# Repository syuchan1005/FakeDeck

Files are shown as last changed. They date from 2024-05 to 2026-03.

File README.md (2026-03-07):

# Fakedeck
Using raspberry pi pico as a stream deck

## Avaiable devices

|Mk2|Plus|
|:--:|:--:|
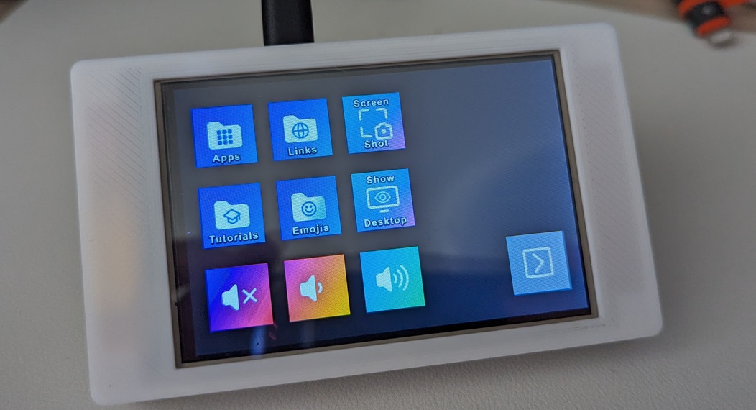
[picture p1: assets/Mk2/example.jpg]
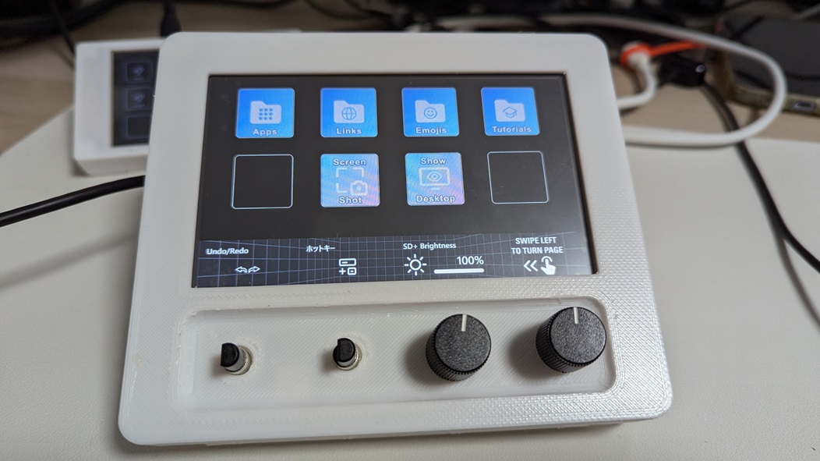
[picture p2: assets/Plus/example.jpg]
|||

## How to create : StreamDeck Mk.2
### Parts
- Raspberry Pi Pico
- ILI9488 TFT with Touch: [AliExpress](https://www.aliexpress.com/item/32985467436.html)
> [!IMPORTANT]
> Make sure to select "touch screen"
- Solder, wire, etc.
- 3D printers for creating a case - [Top](./assets/Mk2/Case%20-%20Top.stl), [Bottom](./assets/Mk2/Case%20-%20Bottom.stl)
- M3 x 6mm screw *4

### Wire
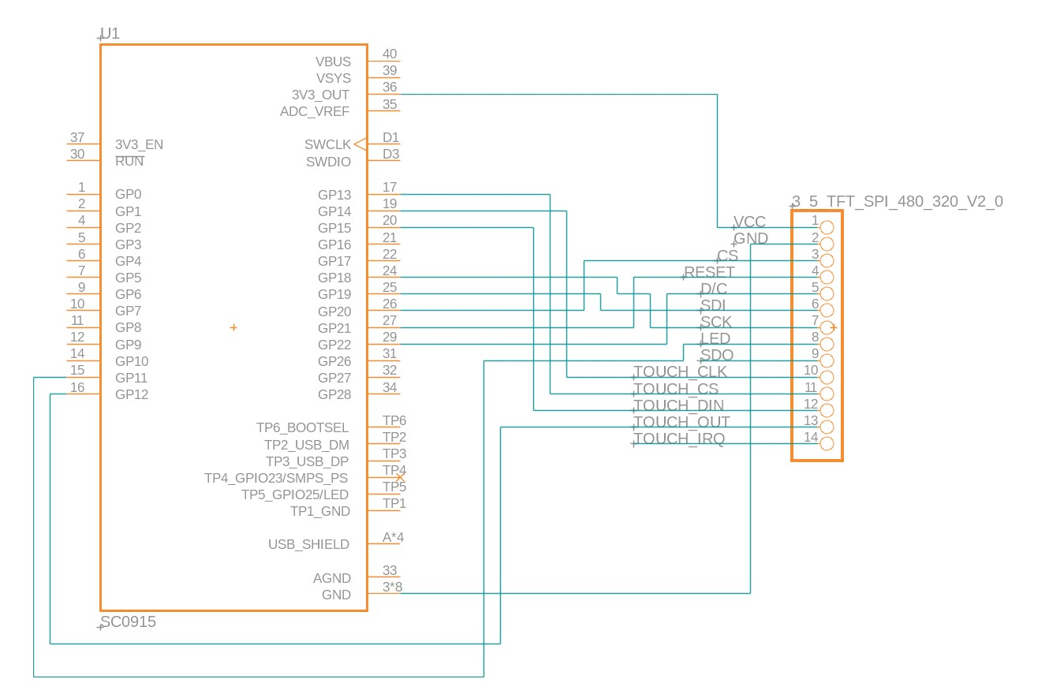
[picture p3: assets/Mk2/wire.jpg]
wire

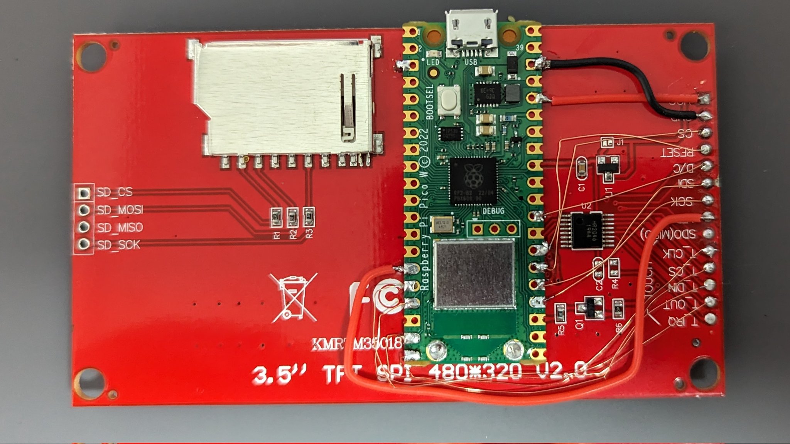
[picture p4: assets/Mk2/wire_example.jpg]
wire example


> [!NOTE]
> LCD uses 90 mA. 
> In the example, the back of the LCD is shaved and soldered to hold the pico in place.

### Build
1. Setup [PlatformIO IDE](https://platformio.org/platformio-ide)
2. Clone and open this project
3. Change environment to `pico_deckMk2`
4. Build .uf2 file!

## How to create : StreamDeck+
### Parts
- Raspberry Pi Pico W
- SSD1963 TFT with Touch: [AliExpress](https://www.aliexpress.com/item/1005006305412643.html)
> [!IMPORTANT]
> Make sure to select "resistive touch"
- Rotary encoder with switch (PEC12R-4220F-S0024) * 4: [Digikey](https://www.digikey.jp/short/jrrh2j7r), [Monotaro](https://www.monotaro.com/p/3483/7593/)
- Stripboard(approx. 120 x 90 (mm)) or Order PCB
- 3D printers for creating a case - [Top](./assets/Plus/Case%20-%20Top.stl), [Bottom body](./assets/Plus/Case%20-%20Bottom%20body.stl), [Bottom base](./assets/Plus/Case%20-%20Bottom%20base.stl), [Bottom bridge](./assets/Plus/Case%20-%20Bottom%20bridge.stl)
- M3 x 6mm screw *4
- Resistors: 47Ω, 120Ω, 220Ω, 470Ω, 1kΩ

> These resistors are used in the switch's ladder circuit. Any other value is acceptable as long as it is a constant multiple of the specified resistance. If using resistors other than these, modify `SW_PATTERNS` in [Encoder.hpp](./src/input/Encoder.hpp).

### Wire
wire_plus
|Front|Back|
|:--:|:--:|
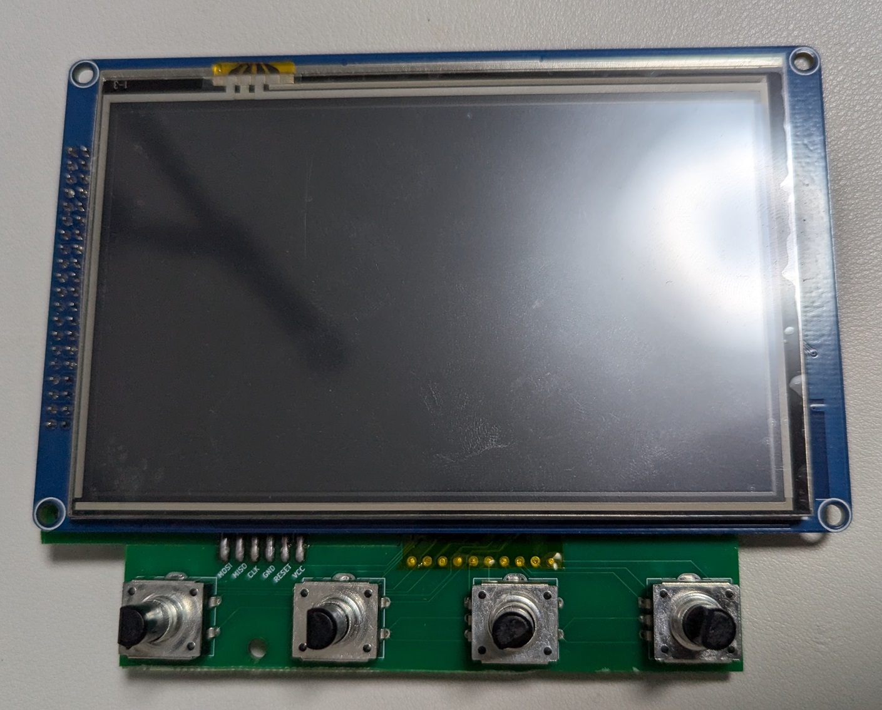
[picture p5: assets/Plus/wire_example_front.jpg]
wire_plus example_front
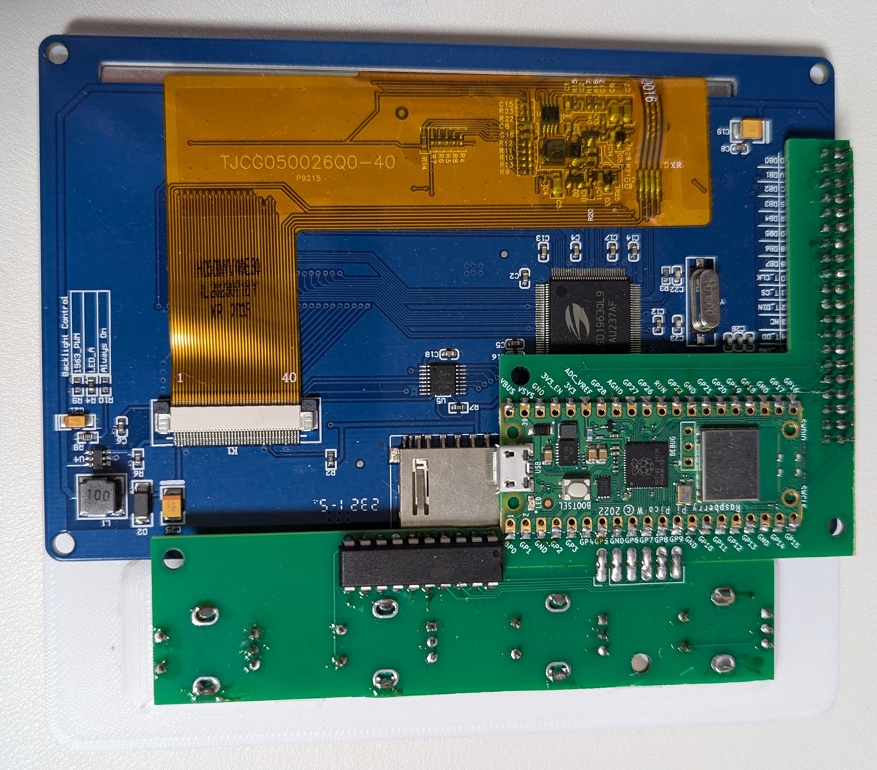
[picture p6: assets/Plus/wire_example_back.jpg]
wire_plus example_back
|||

> These are for the old PCB.

### projects

#### pico_avrisp_wifi
> not used
Write to avr microcontroller (attiny2313) using Raspberry Pi Pico W via WiFi

This project access WiFi AP. You should copy `config.sample.ini` to `config.ini`, and change values to your Wifi settings.

> [!NOTE]
> In my enviroment, [avrdude](https://github.com/avrdudes/avrdude) can not communicate with Raspberry Pi Pico via usb serial. So, It write to avr microcontroller via WiFi.

> [!IMPORTANT]
> In my environment, avrdude 6.3(PlatformIO embedded version) can not write via WiFi. Please update to **^7.3**. (You can replace files in `tool-avrdude` package)

#### avr
> not used
Get the four rotary encoder with push switch values via SPI.

### Build
#### Custom PCB
This project includes the [kicad project](./assets/Plus/kicad).

> [!WARNING]
> It includes gerber files, but they are for the old PCB.

#### Hardware
Solder the rotary encoders with reference to the [kicad project](./assets/Plus/kicad), making sure that the Screen display area is correct before soldering the rotary encoders.

#### Software
1. Setup [PlatformIO IDE](https://platformio.org/platformio-ide)
2. Clone and open this project
3. Change environment to `pico_deckPlus`, build and upload.

## Tips
- [HID Explorer](https://nondebug.github.io/webhid-explorer/) is an easy HID testing tool using WebHID
- Reboot device and enter bootsel mode: Send `[02, FF]` to the output report
- Reboot device: Send `[02, FE]` to the output report

## Reference
- [ESP8266AVRISP](https://github.com/esp8266/Arduino/tree/19b7a29720a6f2c95d06e2ea4baa335dcf32e68f/libraries/ESP8266AVRISP)
- [avr-usi-spi](https://github.com/tessel/avr-usi-spi/blob/77ce496d6bc404684158e619695c2fb7bc76815a/spi_via_usi_driver.c)

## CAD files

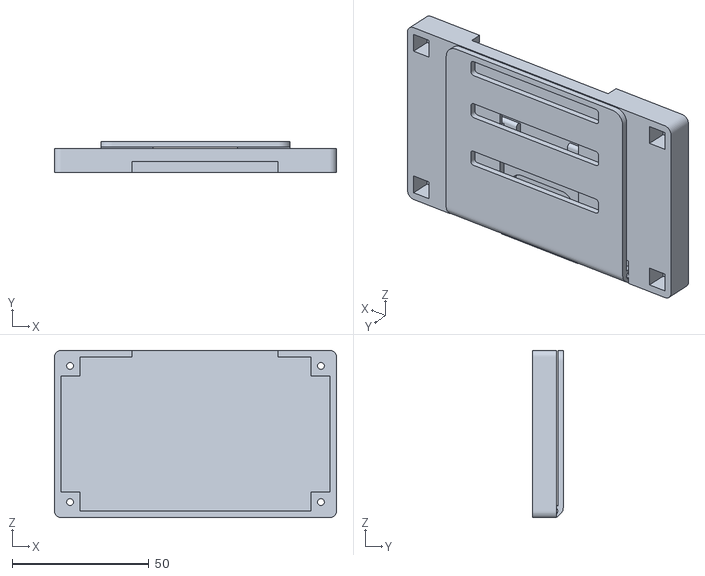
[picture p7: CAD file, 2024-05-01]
assets/Mk2/Case - Bottom.stl
103.3 x 11.2 x 61.3

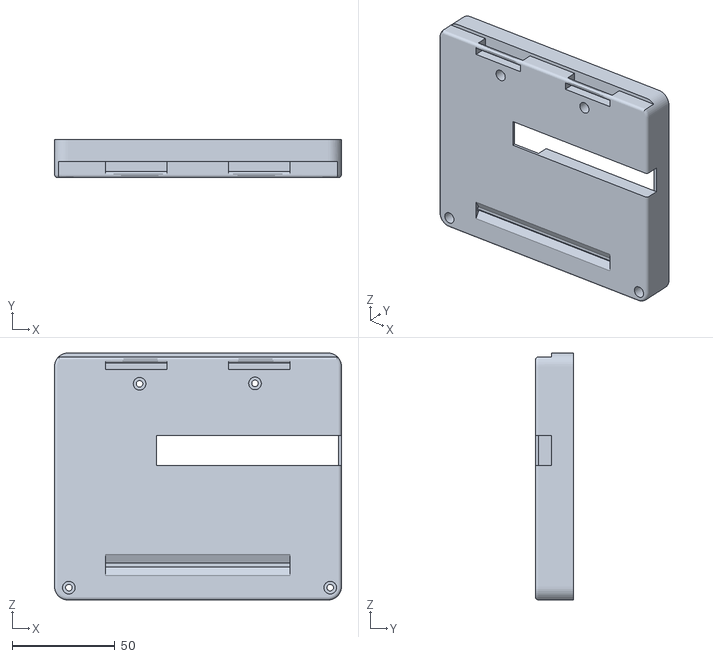
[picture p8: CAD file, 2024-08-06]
assets/Plus/Bottom body.stl
140.0 x 18.7 x 120.4

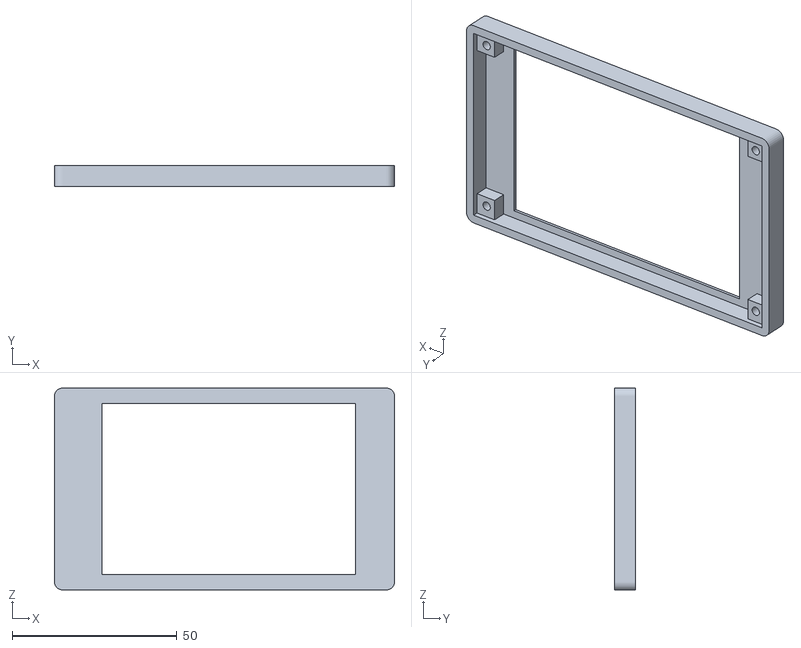
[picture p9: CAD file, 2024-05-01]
assets/Mk2/Case - Top.stl
103.3 x 6.30 x 61.3

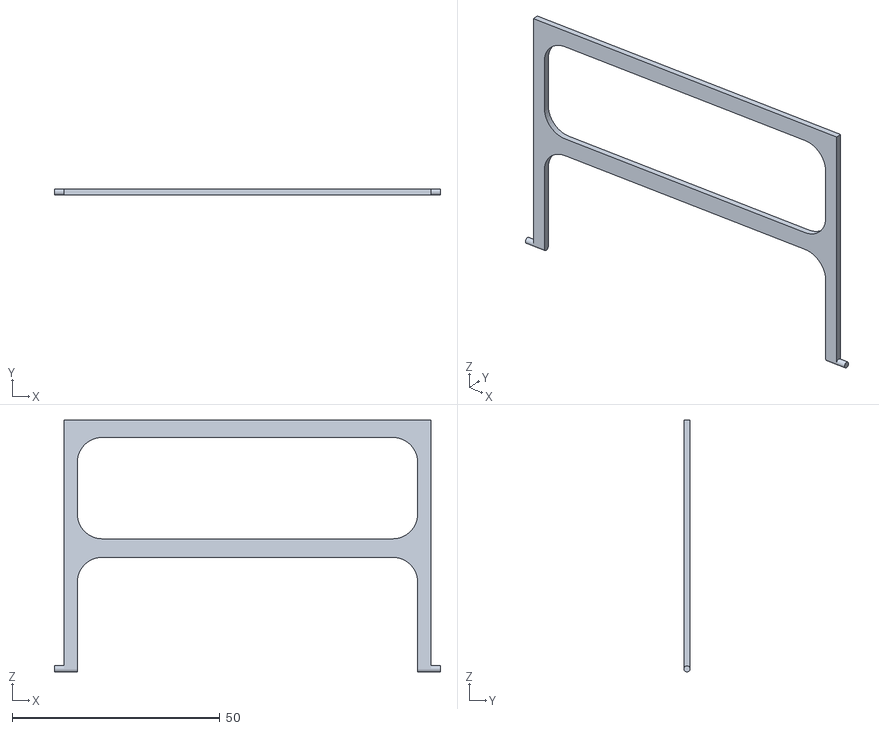
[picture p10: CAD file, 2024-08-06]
assets/Plus/Case - Bottom bridge.stl
93.0 x 1.50 x 60.7

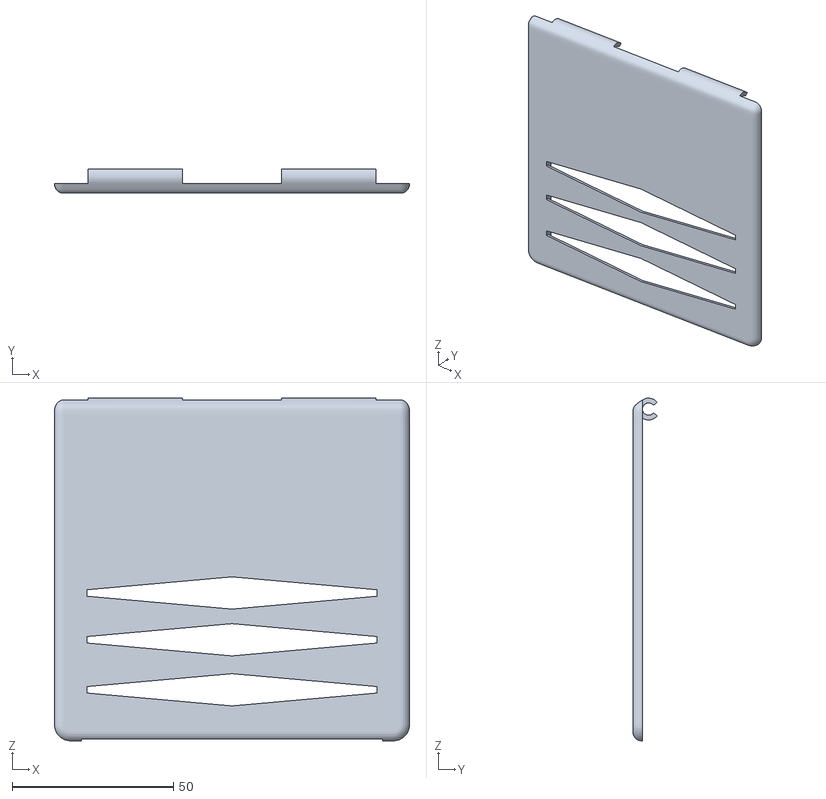
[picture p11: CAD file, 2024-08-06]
assets/Plus/Case - bottom base.stl
110.0 x 7.59 x 106.2

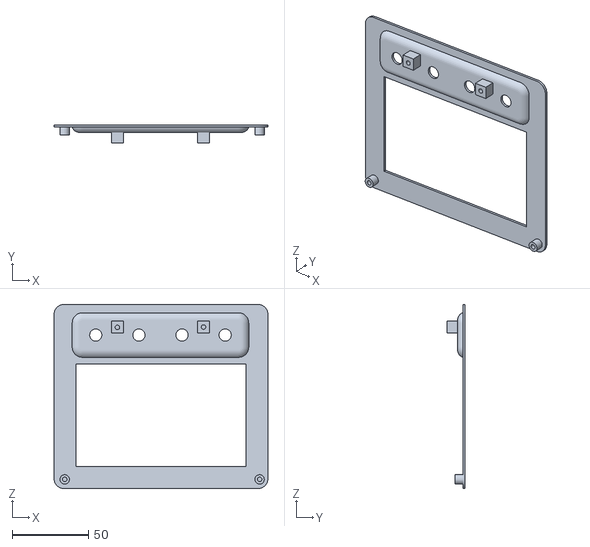
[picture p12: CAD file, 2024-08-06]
assets/Plus/Case - Top.stl
140.0 x 11.9 x 120.4

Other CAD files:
assets/Plus/Case - bottom body.stl
assets/Plus/Case.f3d

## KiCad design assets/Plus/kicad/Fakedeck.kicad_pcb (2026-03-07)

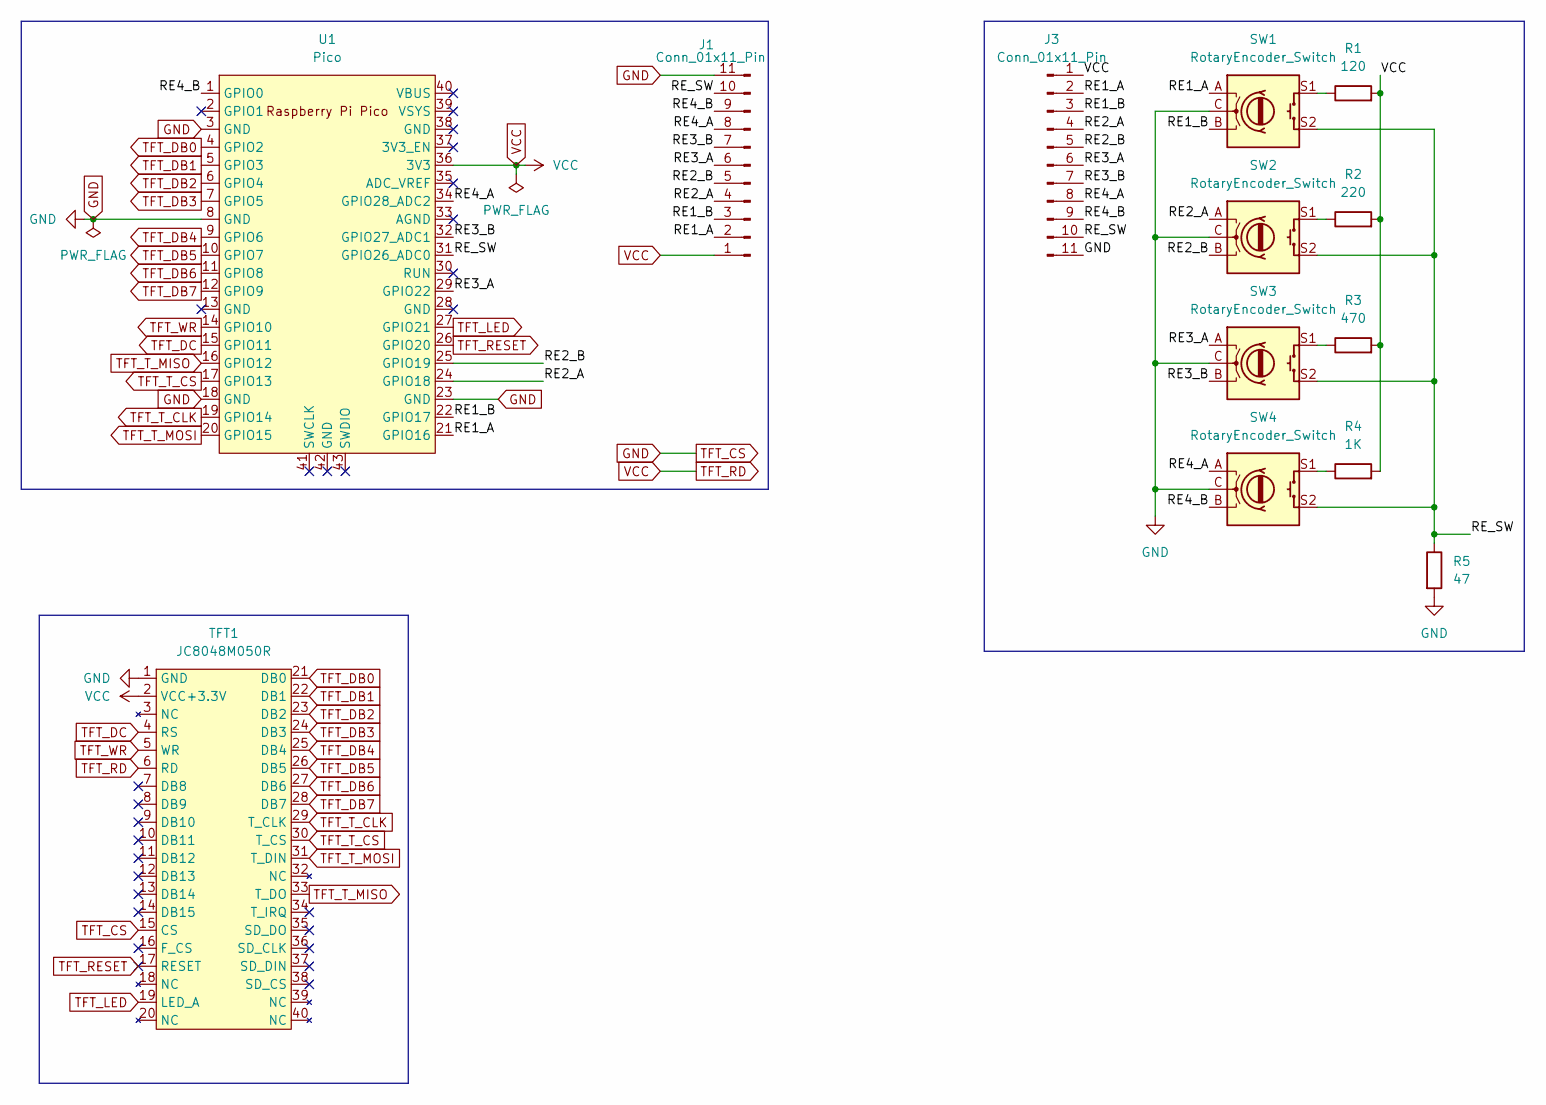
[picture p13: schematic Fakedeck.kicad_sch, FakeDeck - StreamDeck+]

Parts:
J1, J3: Conn_01x11_Pin; PinHeader_Castellated_1x11_P2.54mm_Vertical
R1: 120; R_Axial_DIN0207_L6.3mm_D2.5mm_P7.62mm_Horizontal
R2: 220; R_Axial_DIN0207_L6.3mm_D2.5mm_P7.62mm_Horizontal
R3: 470; R_Axial_DIN0207_L6.3mm_D2.5mm_P7.62mm_Horizontal
R4: 1K; R_Axial_DIN0207_L6.3mm_D2.5mm_P7.62mm_Horizontal
R5: 47; R_Axial_DIN0207_L6.3mm_D2.5mm_P7.62mm_Horizontal
SW1, SW2, SW3, SW4: RotaryEncoder_Switch; 3D_RotaryEncoder_Bourns_Vertical_PEC12R-3x17F-Sxxxx
TFT1: JC8048M050R; JC8048M050R_PinHeader
U1: Pico; RPi_Pico_SMD_TH

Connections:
/RE1_A: J1.2, J3.2, SW1.A, U1.21 (GPIO16)
/RE1_B: J1.3, J3.3, SW1.B, U1.22 (GPIO17)
/RE2_A: J1.4, J3.4, SW2.A, U1.24 (GPIO18)
/RE2_B: J1.5, J3.5, SW2.B, U1.25 (GPIO19)
/RE3_A: J1.6, J3.6, SW3.A, U1.29 (GPIO22)
/RE3_B: J1.7, J3.7, SW3.B, U1.32 (GPIO27_ADC1)
/RE4_A: J1.8, J3.8, SW4.A, U1.34 (GPIO28_ADC2)
/RE4_B: J1.9, J3.9, SW4.B, U1.1 (GPIO0)
/RE_SW: J1.10, J3.10, R5.1, SW1.S2, SW2.S2, SW3.S2, SW4.S2, U1.31 (GPIO26_ADC0)
GND: J1.11, J3.11, R5.2, SW1.C, SW2.C, SW3.C, SW4.C, TFT1.1 (GND), TFT1.15 (CS), U1.3 (GND), U1.8 (GND), U1.18 (GND), U1.23 (GND)
unnamed: R1.1, SW1.S1
unnamed: R2.1, SW2.S1
unnamed: R3.1, SW3.S1
unnamed: R4.1, SW4.S1
TFT_DB0: TFT1.21 (DB0), U1.4 (GPIO2)
TFT_DB1: TFT1.22 (DB1), U1.5 (GPIO3)
TFT_DB2: TFT1.23 (DB2), U1.6 (GPIO4)
TFT_DB3: TFT1.24 (DB3), U1.7 (GPIO5)
TFT_DB4: TFT1.25 (DB4), U1.9 (GPIO6)
TFT_DB5: TFT1.26 (DB5), U1.10 (GPIO7)
TFT_DB6: TFT1.27 (DB6), U1.11 (GPIO8)
TFT_DB7: TFT1.28 (DB7), U1.12 (GPIO9)
TFT_DC: TFT1.4 (RS), U1.15 (GPIO11)
TFT_LED: TFT1.19 (LED_A), U1.27 (GPIO21)
TFT_RD: J1.1, J3.1, R1.2, R2.2, R3.2, R4.2, TFT1.2 (VCC+3.3V), TFT1.6 (RD), U1.36 (3V3)
TFT_RESET: TFT1.17 (RESET), U1.26 (GPIO20)
TFT_T_CLK: TFT1.29 (T_CLK), U1.19 (GPIO14)
TFT_T_CS: TFT1.30 (T_CS), U1.17 (GPIO13)
TFT_T_MISO: TFT1.33 (T_DO), U1.16 (GPIO12)
TFT_T_MOSI: TFT1.31 (T_DIN), U1.20 (GPIO15)
TFT_WR: TFT1.5 (WR), U1.14 (GPIO10)

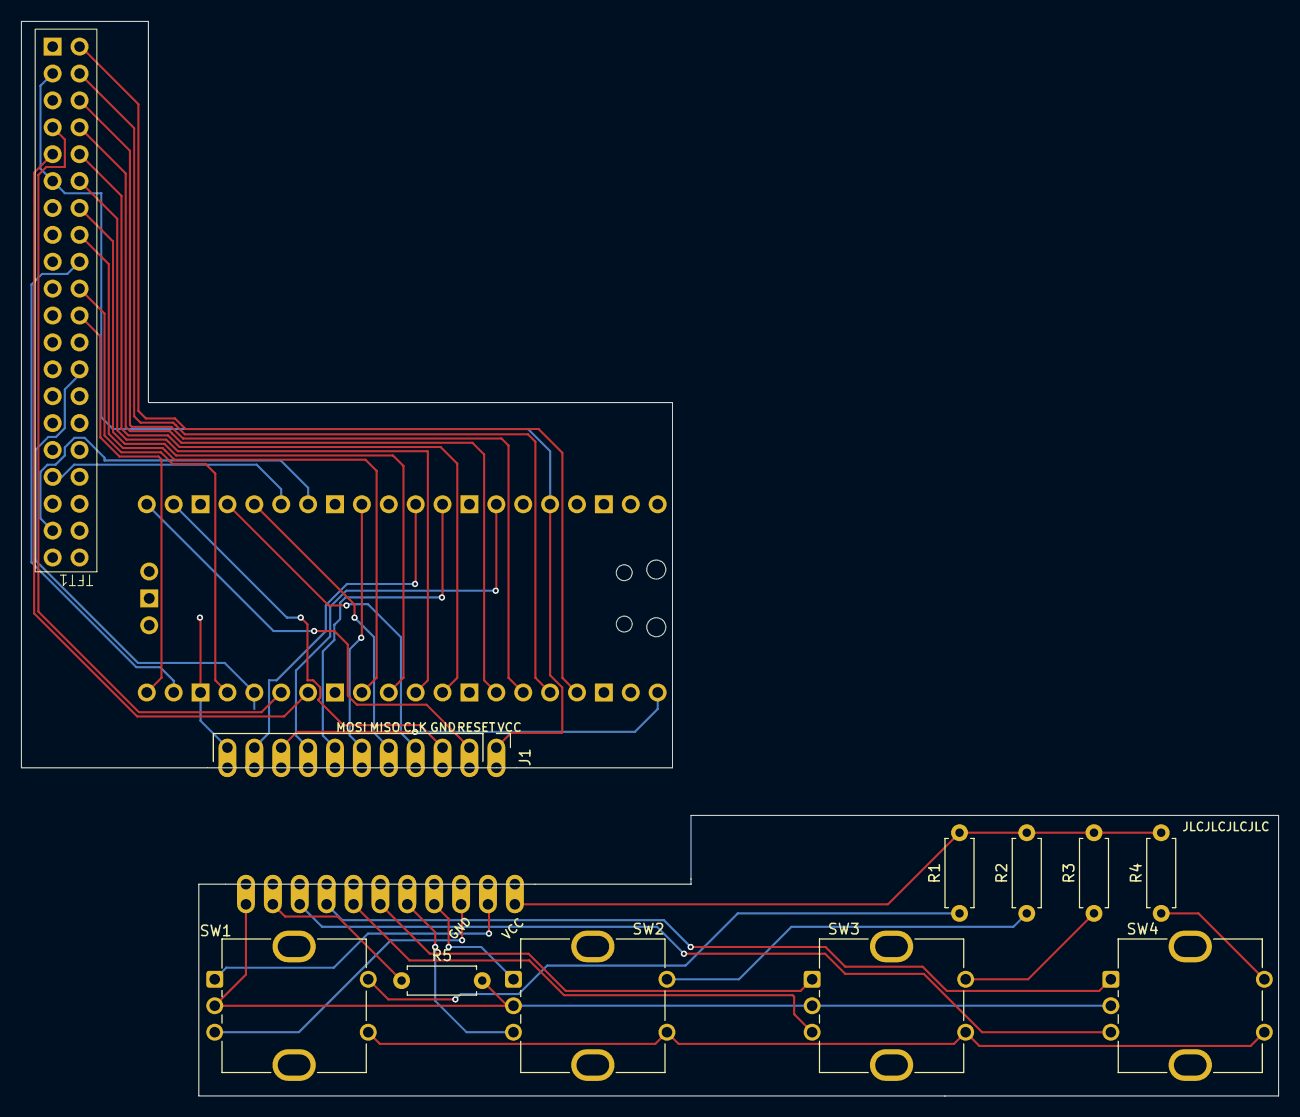
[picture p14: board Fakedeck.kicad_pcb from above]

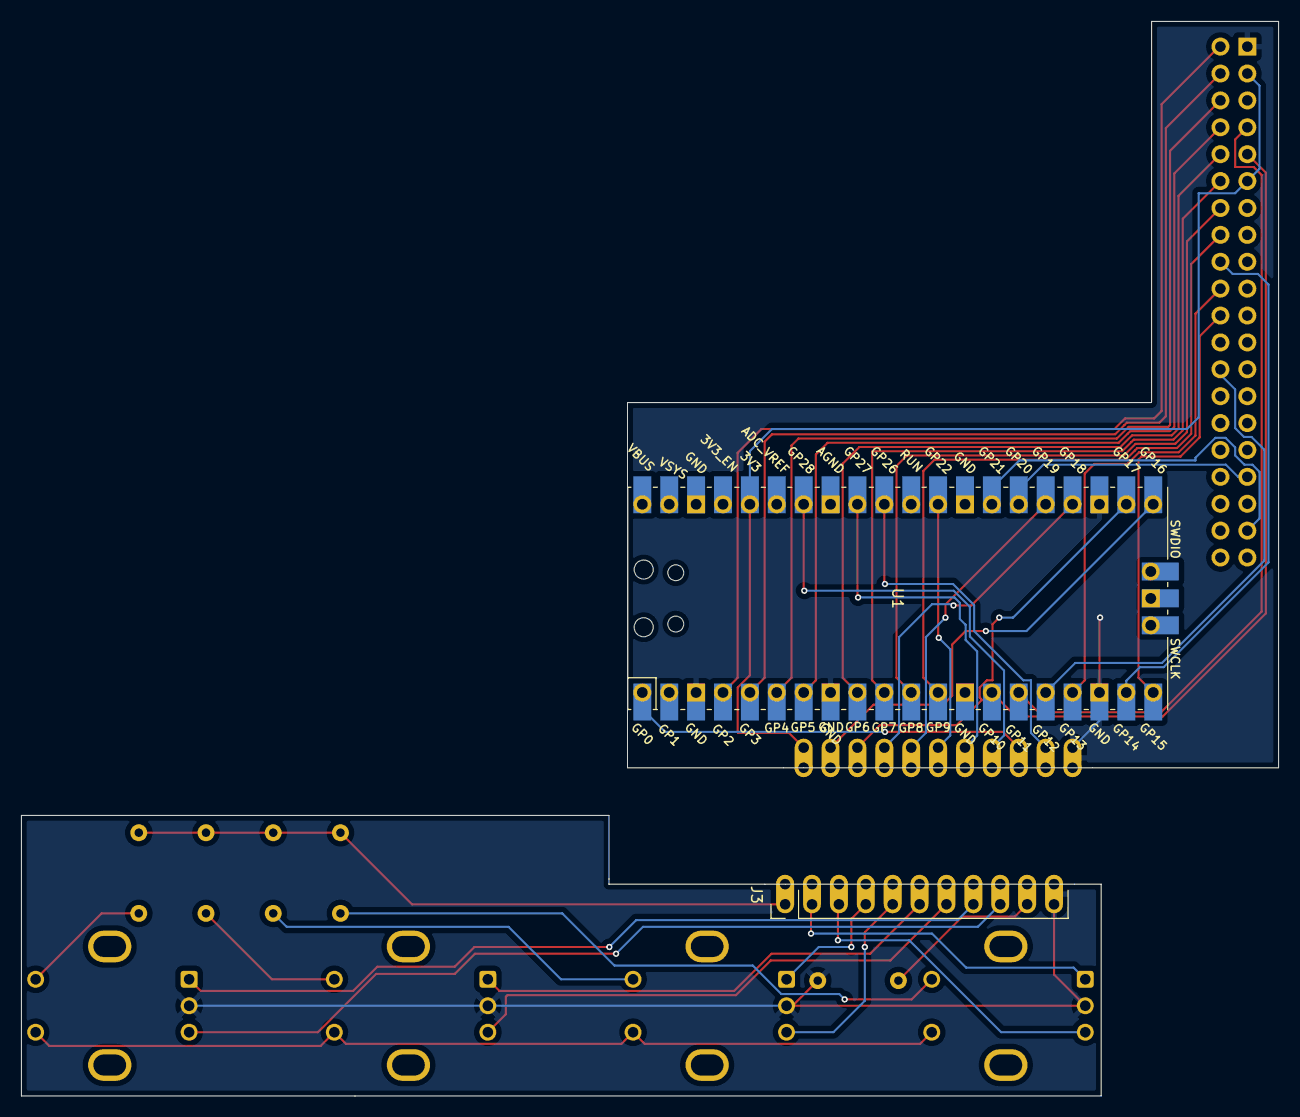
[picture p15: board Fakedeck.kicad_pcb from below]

Board: 2 copper layers, 118.8 x 101.5 mm, 13 parts (2 on the bottom side), 31 nets.

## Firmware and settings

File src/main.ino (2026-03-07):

#include <memory>
#include <algorithm>
#include <Adafruit_TinyUSB.h>
#include "./usb_descriptors.hpp"
#include "./input/LCD.hpp"
#include "./input/Encoder.hpp"
#include "./FileRepository.hpp"

Adafruit_USBD_HID usb_hid;
uint8_t const desc_hid_report[] = {TUD_HID_REPORT_DESC()};

Input::Display::LCD lcd;
Input::Encoder::Encoder encoder;
FileRepository file_repository;

// 6.2.0.18816
uint8_t version[20] = {0x0C, 0xD9, 0x4B, 0x72, 0xE0, 0x36, 0x2E, 0x32, 0x2E, 0x30, 0x2E, 0x31, 0x38, 0x38, 0x31, 0x36, 0x00, 0x00, 0x00};
// ZZZZZZZZZZZZZ
uint8_t serial[20] = {0x0C, 0x00, 0x00, 0x00, 0x00, 0x00, 0x5A, 0x5A, 0x5A, 0x5A, 0x5A, 0x5A, 0x5A, 0x5A, 0x5A, 0x5A, 0x5A, 0x5A, 0x00, 0x00};

queue_t report_packet_queue;
struct report_packet_t
{
    uint8_t report_id;
    hid_report_type_t report_type;
    uint8_t buffer[OUTPUT_REPORT_LEN];
    uint16_t bufsize;
};

queue_t brightness_queue;
queue_t display_event_queue;
queue_t encoder_event_queue;

void setup()
{
    Serial.begin(115200);

    TinyUSBDevice.setManufacturerDescriptor(DECK_USB_MANUFACTURER);
    TinyUSBDevice.setProductDescriptor(DECK_USB_PRODUCT);
    TinyUSBDevice.setID(DECK_USB_VID, DECK_USB_PID);

    usb_hid.enableOutEndpoint(true);
    usb_hid.setPollInterval(2);
    usb_hid.setReportDescriptor(desc_hid_report, sizeof(desc_hid_report));
    usb_hid.setReportCallback(get_report_callback, pre_set_report_callback);
    usb_hid.begin();

    queue_init(&report_packet_queue, sizeof(report_packet_t), 20);
    queue_init(&brightness_queue, sizeof(uint8_t), 2);
    queue_init(&display_event_queue, sizeof(Input::Display::Event::Event), 4);
    queue_init(&encoder_event_queue, sizeof(Input::Encoder::Event::Event), 4);
}

// WARNING: We should not use `wait` function (e.g. `delay`) in this function. TinyUSB's tud_task should be called in the loop. And it's needed to be called very frequently.
void loop()
{
    Input::Display::Event::Event event = Input::Display::Event::NONE_OBJ;
    if (queue_try_remove(&display_event_queue, &event))
    {
        Serial.printf("Event { type: %d, keyIndex: %d, x: %d, y: %d, x_out: %d, y_out: %d }\n", event.type, event.keyIndex, event.x, event.y, event.x_out, event.y_out);
        switch (event.type)
        {
        case Input::Display::Event::NONE:
        {
            Serial.println("No Key Pressed");
            uint8_t report[INPUT_REPORT_LEN] = {0, KEY_COUNT, 0};
            usb_hid.sendReport(1, report, sizeof(report));
            break;
        }
        case Input::Display::Event::KEY_PRESSED:
        {
            Serial.printf("Pressed Key: %d\n", event.keyIndex);
            uint8_t report[INPUT_REPORT_LEN] = {0, KEY_COUNT, 0};
            report[event.keyIndex + 3] = 1;
            usb_hid.sendReport(1, report, sizeof(report));
            break;
        }
#if defined(DECK_TOUCH)
        case Input::Display::Event::TOUCH_PRESSED_SHORT:
        {
            uint8_t touchReport[INPUT_REPORT_LEN] =
                {0x02, DIAL_COUNT, 0x00,
                 0x01, 0x00, U16_TO_U8S_LE(event.x), U16_TO_U8S_LE(event.y), 0x00};
            usb_hid.sendReport(1, touchReport, sizeof(touchReport));
            break;
        }
        case Input::Display::Event::TOUCH_PRESSED_LONG:
        {
            uint8_t touchReport[INPUT_REPORT_LEN] =
                {0x02, DIAL_COUNT, 0x00,
                 0x02, 0x00, U16_TO_U8S_LE(event.x), U16_TO_U8S_LE(event.y), 0x00};
            usb_hid.sendReport(1, touchReport, sizeof(touchReport));
            break;
        }
        case Input::Display::Event::TOUCH_DRAG:
        {
            uint8_t touchReport[INPUT_REPORT_LEN] =
                {0x02, DIAL_COUNT, 0x00,
                 0x03, 0x00, U16_TO_U8S_LE(event.x), U16_TO_U8S_LE(event.y), U16_TO_U8S_LE(event.x_out), U16_TO_U8S_LE(event.y_out), 0x00};
            usb_hid.sendReport(1, touchReport, sizeof(touchReport));
            break;
        }
#endif
        default:
            Serial.printf("Unknown Display Event: %d\n", event.type);
            break;
        }
    }
#if defined(DECK_TOUCH)
    Input::Encoder::Event::Event encoderEvent = Input::Encoder::Event::Event(Input::Encoder::Event::EventType::NONE, 0);
    if (queue_try_remove(&encoder_event_queue, &encoderEvent))
    {
        Serial.printf("Encoder Event { type: %d, value: ", encoderEvent.type);
        Serial.print(encoderEvent.value, BIN);
        Serial.println(" }");
        switch (encoderEvent.type)
        {
        case Input::Encoder::Event::EventType::TURN:
        {
            uint8_t report[INPUT_REPORT_LEN] =
                {0x03, DIAL_COUNT + 1, 0x00,
                 0x01,
                 (uint8_t)make_encoder_turn_report(encoderEvent.value),
                 (uint8_t)make_encoder_turn_report(encoderEvent.value >> 2),
                 (uint8_t)make_encoder_turn_report(encoderEvent.value >> 4),
                 (uint8_t)make_encoder_turn_report(encoderEvent.value >> 6),
                 0x00};
            usb_hid.sendReport(1, report, sizeof(report));
            break;
        }
        case Input::Encoder::Event::EventType::PRESS:
        {
            uint8_t report[INPUT_REPORT_LEN] =
                {0x03, DIAL_COUNT + 1, 0x00,
                 0x00,
                 encoderEvent.value & 1,
                 encoderEvent.value & (1 << 1),
                 encoderEvent.value & (1 << 2),
                 encoderEvent.value & (1 << 3),
                 0x00};
            Serial.print("report:");
            for (int i = 0; i < INPUT_REPORT_LEN; i++)
            {
                Serial.print(report[i], HEX);
                Serial.print(" ");
            }
            Serial.println();

            usb_hid.sendReport(1, report, sizeof(report));
            break;
        }

        default:
            Serial.printf("Unknown Encoder Event: %d\n", encoderEvent.type);
            break;
        }
    }
#endif
}

uint8_t reverse(uint8_t num)
{
    uint8_t reverse_num = 0;
    for (uint8_t i = 0; i < 8; i++)
    {
        if ((num & (1 << i)))
            reverse_num |= 1 << (7 - i);
    }
    return reverse_num;
}

int8_t make_encoder_turn_report(uint8_t turn)
{
    switch (turn & 0x03)
    {
    case 1:
        return -1; // turn left
    case 2:
        return 1; // turn right
    default:
    case 3:
        return 0; // no turn
    }
}

void setup1()
{
    lcd.init();
    file_repository.init();
    lcd.calibrate(file_repository);

    encoder.init();
}

void loop1()
{
    report_packet_t packet;
    if (queue_try_remove(&report_packet_queue, &packet))
    {
        set_report_callback(packet.report_id, packet.report_type, packet.buffer, packet.bufsize);
    }

    uint8_t brightness;
    if (queue_try_remove(&brightness_queue, &brightness))
    {
        lcd.set_brightness(brightness);
    }

    maybe_send_event();
}

Input::Display::Event::Event previous_event = Input::Display::Event::NONE_OBJ;
uint32_t previous_executed_event_millis = 0;
void maybe_send_event()
{
    uint32_t current_millis = millis();
    if (current_millis - previous_executed_event_millis < 10)
    {
        return;
    }
    previous_executed_event_millis = current_millis;
    Input::Display::Event::Event event = lcd.get_event();
    if (previous_event.type != event.type)
    {
        queue_add_blocking(&display_event_queue, &event);
        if (event.type == Input::Display::Event::EventType::KEY_PRESSED)
            previous_event = event;
        else
            previous_event = Input::Display::Event::NONE_OBJ;
    }

    maybe_send_encoder_event();
}

Input::Encoder::Event::EventDataHolder previous_encoder_event_data_holder = Input::Encoder::Event::EventDataHolder(0, 0);
void maybe_send_encoder_event()
{
    Input::Encoder::Event::EventDataHolder eventDataHolder = encoder.get_event();
    // turn is consumed (cleared) each call, so send whenever non-zero rather than
    // comparing with previous value (which would fire twice: once on turn, once on reset to 0).
    if (eventDataHolder.turn != 0)
    {
        Input::Encoder::Event::Event event = Input::Encoder::Event::Event(Input::Encoder::Event::EventType::TURN, eventDataHolder.turn);
        queue_add_blocking(&encoder_event_queue, &event);
    }
    if (previous_encoder_event_data_holder.press != eventDataHolder.press)
    {
        Input::Encoder::Event::Event event = Input::Encoder::Event::Event(Input::Encoder::Event::EventType::PRESS, eventDataHolder.press);
        queue_add_blocking(&encoder_event_queue, &event);
    }
    previous_encoder_event_data_holder = eventDataHolder;
}

uint16_t get_report_callback(uint8_t report_id, hid_report_type_t report_type, uint8_t *buffer, uint16_t reqlen)
{
    (void)buffer;
    (void)reqlen;

    Serial.printf("GET Report Type: %d, Report ID: %d\n", report_type, report_id);

    if (report_type == HID_REPORT_TYPE_FEATURE)
    {

        if (report_id == 0x05)
        {
            // version
            std::copy_n(version, reqlen, buffer);
            return sizeof(buffer) * 8 - 1;
        }
        else if (report_id == 0x06)
        {
            // serial
            std::copy_n(serial, reqlen, buffer);
            return sizeof(buffer) * 8 - 1;
        }
    }

    return 0;
}

uint8_t output_report_id = 0;
uint8_t output_report_buffer[OUTPUT_REPORT_LEN];
uint16_t output_report_written_len = 0;

// Invoked when received SET_REPORT control request or received data on OUT endpoint ( Report ID = 0, Type = 0 )
void pre_set_report_callback(uint8_t report_id, hid_report_type_t report_type, uint8_t const *buffer, uint16_t bufsize)
{
    char str[150];
    sprintf(
        str,
        "SET Report Type: %d, Report ID: %d, len: %d, outputlen: %04d, buf: [%02X, %02X, %02X, %02X, %02X, %02X, ...]",
        report_type, report_id, bufsize, output_report_written_len,
        buffer[0], buffer[1], buffer[2], buffer[3], buffer[4], buffer[5]);
    Serial.println(str);

    // Handle OUTPUT report
    // When report_type == OUTPUT (2) with report_id == 0, buffer[0] contains the actual report ID
    if (report_type == HID_REPORT_TYPE_OUTPUT && report_id == 0 &&
        (buffer[0] == OUTPUT_REPORT_ID || output_report_written_len > 0))
    {
        if (output_report_written_len == 0)
        {
            // First packet: buffer[0] is report ID, buffer[1] is command
            output_report_id = buffer[0];
            std::copy_n(buffer + 1, bufsize - 1, output_report_buffer);
            output_report_written_len = bufsize - 1;
            Serial.printf("OUTPUT START: id=%02X, cmd=%02X, len=%d\n", output_report_id, buffer[1], bufsize - 1);
        }
        else
        {
            // Continuation packet: all data
            std::copy_n(buffer, bufsize, output_report_buffer + output_report_written_len);
            output_report_written_len += bufsize;
            Serial.printf("OUTPUT CONT: total=%d\n", output_report_written_len);
        }

        if (output_report_written_len >= OUTPUT_REPORT_LEN)
        {
            Serial.printf("OUTPUT COMPLETE: %d bytes, cmd=%02X\n", output_report_written_len, output_report_buffer[0]);
            emit_report_packet(output_report_id, HID_REPORT_TYPE_OUTPUT, output_report_buffer, output_report_written_len);
            output_report_written_len = 0;
        }
        return;
    }

    // If it processes output report, but, another report type will come.
    if (output_report_written_len > 0 && report_type != HID_REPORT_TYPE_OUTPUT)
    {
        // reset output report buffer
        output_report_written_len = 0;
    }

    emit_report_packet(report_id, report_type, buffer, bufsize);
}

void emit_report_packet(uint8_t report_id, hid_report_type_t report_type, uint8_t const *buffer, uint16_t bufsize)
{
    report_packet_t packet;
    packet.report_id = report_id;
    packet.report_type = report_type;
    std::copy_n(buffer, bufsize, packet.buffer);
    packet.bufsize = bufsize;
    queue_try_add(&report_packet_queue, &packet);
}

uint8_t image_type = 0; // 0x07: key, 0x0C: touchscreen
uint8_t image_buffer[MAX_IMAGE_SIZE_BYTES];
uint16_t image_buffer_written_len = 0;

void set_report_callback(uint8_t report_id, hid_report_type_t report_type, uint8_t const *buffer, uint16_t bufsize)
{
    if (report_type == HID_REPORT_TYPE_FEATURE)
    {
        if (report_id == 0x03 && buffer[0] == 0x02)
        {
            Serial.println("Reset");
        }
        else if (report_id == 0x03 && buffer[0] == 0x08)
        {
            queue_add_blocking(&brightness_queue, &buffer[1]);
        }
    }

    if (report_type == HID_REPORT_TYPE_OUTPUT)
    {
        Serial.printf("Output Report: %d, %d, [%02X, %02X, %02X, %02X, %02X, %02X]\n", report_id, bufsize, buffer[0], buffer[1], buffer[2], buffer[3], buffer[4], buffer[5]);

        // reset image buffer when another request comes
        if (report_id == 0x02 && image_buffer_written_len > 0 && buffer[0] != image_type)
        {
            image_buffer_written_len = 0;
        }

        if (report_id == 0x02 && buffer[0] == 0x07)
        {
            // key image
            image_type = buffer[0];
            uint8_t key_index = buffer[1];
            uint8_t is_last = buffer[2];
            uint16_t image_length = buffer[3] | (buffer[4] << 8);
            uint16_t page_number = buffer[5] | (buffer[6] << 8);

            if (image_buffer_written_len + image_length <= MAX_IMAGE_SIZE_BYTES)
            {
                std::copy_n(buffer + 7, image_length, image_buffer + image_buffer_written_len);
                image_buffer_written_len += image_length;
            }
            else
            {
                Input::Display::tft.fillRect(0, 0, 50, 50, TFT_RED);
            }

            if (is_last)
            {
                Serial.printf("Draw image: %d\n", key_index);
                lcd.draw_key_image(key_index, image_buffer, image_buffer_written_len);
                image_buffer_written_len = 0;
            }
        }
        else if (report_id == 0x02 && buffer[0] == 0x0C)
        {
            // touchscreen image
            image_type = buffer[0];
            uint16_t x_pos = buffer[1] | (buffer[2] << 8);
            uint16_t y_pos = buffer[3] | (buffer[4] << 8);
            // uint16_t width = buffer[5] | (buffer[6] << 8);
            // uint16_t height = buffer[7] | (buffer[8] << 8);
            uint8_t is_last = buffer[9];
            uint16_t page_number = buffer[10] | (buffer[11] << 8);
            uint16_t image_length = buffer[12] | (buffer[13] << 8);
            // padding = buffer[14]

            if (image_buffer_written_len + image_length <= MAX_IMAGE_SIZE_BYTES)
            {
                std::copy_n(buffer + 15, image_length, image_buffer + image_buffer_written_len);
                image_buffer_written_len += image_length;
            }
            else
            {
                Input::Display::tft.fillRect(0, 50, 50, 50, TFT_GREEN);
            }

            if (is_last)
            {
                lcd.draw_touch_image(x_pos, y_pos, image_buffer, image_buffer_written_len);
                image_buffer_written_len = 0;
            }
        }
        else if (report_id == 0x02 && buffer[0] == 0xFF)
        {
            rp2040.rebootToBootloader();
        }
        else if (report_id == 0x02 && buffer[0] == 0xFE)
        {
            rp2040.reboot();
        }
    }
}

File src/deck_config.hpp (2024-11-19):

#ifndef DECK_CONFIG_HPP
#define DECK_CONFIG_HPP

#define ORIGINAL_MK2 1
#define PLUS 2

#if DECK == ORIGINAL_MK2

// This is workaround for the platformio "-include" build flag
#include "../tft-user-config/StreamDeckOriginalMk2Config.hpp"

#define DECK_USB_PID 0x006d
#define DECK_USB_PRODUCT "Streamdeck"

#define KEY_COUNT_COL 5
#define KEY_COUNT_ROW 3
#define KEY_IMAGE_SIZE 72
#define KEY_ORDER_REVERSE

// #define DIAL_COUNT 0

// #define DECK_TOUCH
// #define TOUCHSCREEN_PIXEL_WIDTH 0
// #define TOUCHSCREEN_PIXEL_HEIGHT 0

#define INPUT_REPORT_LEN KEY_COUNT_COL *KEY_COUNT_ROW + 4

#define KEY_H_GAP(w) ((w) - (KEY_IMAGE_SIZE * KEY_COUNT_COL)) / (KEY_COUNT_COL + 1)
#define KEY_V_GAP(h) ((h) - (KEY_IMAGE_SIZE * KEY_COUNT_ROW)) / (KEY_COUNT_ROW + 1)
#define KEY_OFFSET_X(w) KEY_H_GAP(w)
#define KEY_OFFSET_Y(h) KEY_V_GAP(h)

#elif DECK == PLUS

// This is workaround for the platformio "-include" build flag
#include "../tft-user-config/StreamDeckPlusConfig.hpp"

#define DECK_USB_PID 0x0084
#define DECK_USB_PRODUCT "Streamdeck +"

#define KEY_COUNT_COL 4
#define KEY_COUNT_ROW 2
#define KEY_IMAGE_SIZE 120

#define DIAL_COUNT 4

#define DECK_TOUCH
#define TOUCHSCREEN_PIXEL_WIDTH 200
#define TOUCHSCREEN_PIXEL_HEIGHT 100

#define INPUT_REPORT_LEN 14

#define KEY_H_GAP(w) ((w) - (KEY_IMAGE_SIZE * KEY_COUNT_COL)) / (KEY_COUNT_COL + 1)
#define KEY_V_GAP(h) ((h) - (KEY_IMAGE_SIZE * KEY_COUNT_ROW + TOUCHSCREEN_PIXEL_HEIGHT)) / (KEY_COUNT_ROW + 1)
#define KEY_OFFSET_X(w) KEY_H_GAP(w)
#define KEY_OFFSET_Y(h) (KEY_V_GAP(h) / 2)
#define TOUCH_OFFSET_Y(h) h - TOUCHSCREEN_PIXEL_HEIGHT
#define TOUCH_NORMALIZED_Y(h, y) map(y, TOUCH_OFFSET_Y(h), h, 0, TOUCHSCREEN_PIXEL_HEIGHT)

#else
#error "Invalid DECK value"
#endif

#define KEY_X(w, keyIndex) KEY_OFFSET_X(w) + (KEY_IMAGE_SIZE + KEY_H_GAP(w)) * (keyIndex % KEY_COUNT_COL)
#define KEY_Y(h, keyIndex) KEY_OFFSET_Y(h) + (KEY_IMAGE_SIZE + KEY_V_GAP(h)) * (keyIndex / KEY_COUNT_COL)

#endif // DECK_CONFIG_HPP

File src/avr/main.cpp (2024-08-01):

#include <Arduino.h>
#include "./RotaryEncoder.hpp"
#include "./SPISlave.hpp"

void setup()
{
    // set system clock prescaler start(0x80) -> /1(0x00), /8(0x03)
    CLKPR = 0x80;
    CLKPR = 0x00;

    initRotaryEncoders();

    spiX_initslave(0);
    sei(); // Enable interrupts
}

/**
 * stored data
 * inputData, oldInputData: Uses lower 8bit : 0b[SW4_B][SW4_A][SW3_B][SW3_A][SW2_B][SW2_A][SW1_B][SW1_A]
 * sendData:
 *   Upper 8bit - push switch status : 0b0000[SW4][SW3][SW2][SW1]
 *   Lower 8bit - rotary encoder status : 0b[SW4_Left][SW4_Right][SW3_Left][SW3_Right][SW2_Left][SW2_Right][SW1_Left][SW1_Right]
 */
uint16_t inputData = 0;
uint16_t oldInputData = 0;

void loop()
{
    oldInputData = inputData;

    inputData = 0;
    createRotaryEncoderData(0, RE1_PR_DATA_REG, RE1_A, RE1_B, RE1_PR_DATA_REG_S, RE1_S, &inputData, &oldInputData, &sendData);
    createRotaryEncoderData(1, RE2_PR_DATA_REG, RE2_A, RE2_B, RE2_PR_DATA_REG, RE2_S, &inputData, &oldInputData, &sendData);
    createRotaryEncoderData(2, RE3_PR_DATA_REG, RE3_A, RE3_B, RE3_PR_DATA_REG, RE3_S, &inputData, &oldInputData, &sendData);
    createRotaryEncoderData(3, RE4_PR_DATA_REG, RE4_A, RE4_B, RE4_PR_DATA_REG_S, RE4_S, &inputData, &oldInputData, &sendData);

    delay(2);
}

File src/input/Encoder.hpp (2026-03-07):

#ifndef ENCODER_HPP
#define ENCODER_HPP

#include <Arduino.h>
#include "./usb_descriptors.hpp"

// Encoder GPIO pin assignments (replaces ATtiny2313 + SPI)
// These pins are freed from SPI0 (GP16-19) + remaining available GPIOs
#define ENC1_A 16
#define ENC1_B 17
#define ENC2_A 18
#define ENC2_B 19
#define ENC3_A 22
#define ENC3_B 27
#define ENC4_A 28
#define ENC4_B 0
// GP0 is safe to use as GPIO: arduino-pico maps Serial to USB CDC, not UART0.
// UART0 is Serial1, so GP0/GP1 are free for general GPIO use.

// SW inputs: all 4 push switches share a single ADC pin via a binary-weighted
// resistor ladder. Each switch has a resistor with 2^n weighting (1k, 2k, 4k, 8k).
// The ADC value uniquely identifies any combination of pressed switches (16 patterns).
#define ENC_SW_ADC 26  // ADC0 (GP26)

namespace Input
{
    namespace Encoder
    {
        namespace Event
        {
            class EventDataHolder
            {
            public:
                EventDataHolder(uint8_t turn, uint8_t press) : turn(turn), press(press) {}
                uint8_t turn;
                uint8_t press;
            };

            enum EventType
            {
                NONE,
                TURN,
                PRESS
            };

            class Event
            {
            public:
                Event(EventType type, uint8_t value) : type(type), value(value) {}
                EventType type;
                uint8_t value;
            };
        };

        // Accumulated rotation deltas, updated by GPIO interrupts on Core1.
        // Declared volatile because they are written in ISRs and read in get_event().
        volatile int8_t enc_delta[4] = {0, 0, 0, 0};

        // Gray-code state machine for robust quadrature decoding.
        // Tracks the last AB state per encoder to detect valid transitions only.
        // prev_ab[i] holds the previous 2-bit AB value (bit1=A, bit0=B).
        //
        // Valid transition table (standard quadrature):
        //   CW  sequence: 00 → 10 → 11 → 01 → 00  (A leads B)
        //   CCW sequence: 00 → 01 → 11 → 10 → 00  (B leads A)
        //
        // transition_table[prev][curr]:
        //   +1 = CW step, -1 = CCW step, 0 = no change / invalid (bounce)
        static const int8_t transition_table[4][4] = {
            // curr: 00   01   10   11
            {  0,  -1,  +1,   0 }, // prev=00
            { +1,   0,   0,  -1 }, // prev=01
            { -1,   0,   0,  +1 }, // prev=10
            {  0,  +1,  -1,   0 }, // prev=11
        };

        volatile uint8_t prev_ab[4] = {0, 0, 0, 0};

        void isr_enc1()
        {
            uint8_t ab = (digitalRead(ENC1_A) << 1) | digitalRead(ENC1_B);
            enc_delta[0] += transition_table[prev_ab[0]][ab];
            prev_ab[0] = ab;
        }

        void isr_enc2()
        {
            uint8_t ab = (digitalRead(ENC2_A) << 1) | digitalRead(ENC2_B);
            enc_delta[1] += transition_table[prev_ab[1]][ab];
            prev_ab[1] = ab;
        }

        void isr_enc3()
        {
            uint8_t ab = (digitalRead(ENC3_A) << 1) | digitalRead(ENC3_B);
            enc_delta[2] += transition_table[prev_ab[2]][ab];
            prev_ab[2] = ab;
        }

        void isr_enc4()
        {
            uint8_t ab = (digitalRead(ENC4_A) << 1) | digitalRead(ENC4_B);
            enc_delta[3] += transition_table[prev_ab[3]][ab];
            prev_ab[3] = ab;
        }

        // Lookup table for the binary-weighted resistor ladder SW detection.
        // Each SW connects 3.3V through its weight resistor to the ADC node.
        // A pull-down resistor (1kΩ) connects the ADC node to GND.
        // SW weights: SW1=1kΩ, SW2=2kΩ, SW3=4kΩ, SW4=8kΩ, pull-down=1kΩ.
        //
        // Voltage when switches pressed: V = 3.3 * R_pull / (R_parallel + R_pull)
        // where R_parallel is the parallel combination of pressed switch resistors.
        //
        // ADC values (12-bit, 0-4095) computed from the resistor network.
        // These are theoretical values; fine-tune from real measurements if needed.
        struct SwPattern
        {
            uint16_t adc_val;
            uint8_t mask; // bit0=SW1, bit1=SW2, bit2=SW3, bit3=SW4
        };

        // ADC values computed for: SW1=120Ω, SW2=220Ω, SW3=470Ω, SW4=1kΩ, R_pull=47Ω
        // Formula: V = 3.3 * R_pull / (R_parallel + R_pull), ADC = V/3.3 * 4095
        // Min separation between adjacent patterns: 64 counts → safe margin ±32
        // Sorted ascending by ADC value for binary-search friendliness.
        const SwPattern SW_PATTERNS[16] = {
            {   0, 0b0000}, // none
            { 184, 0b1000}, // SW4
            { 372, 0b0100}, // SW3
            { 525, 0b1100}, // SW3+SW4
            { 721, 0b0010}, // SW2
            { 847, 0b1010}, // SW2+SW4
            { 978, 0b0110}, // SW2+SW3
            {1085, 0b1110}, // SW2+SW3+SW4
            {1152, 0b0001}, // SW1
            {1249, 0b1001}, // SW1+SW4
            {1350, 0b0101}, // SW1+SW3
            {1434, 0b1101}, // SW1+SW3+SW4
            {1544, 0b0011}, // SW1+SW2
            {1617, 0b1011}, // SW1+SW2+SW4
            {1694, 0b0111}, // SW1+SW2+SW3
            {1758, 0b1111}, // all
        };

        uint8_t read_sw_state()
        {
            uint16_t adc = analogRead(ENC_SW_ADC);
            uint8_t best_mask = 0;
            uint16_t best_diff = 0xFFFF;
            for (const auto &p : SW_PATTERNS)
            {
                uint16_t diff = (uint16_t)abs((int)adc - (int)p.adc_val);
                if (diff < best_diff)
                {
                    best_diff = diff;
                    best_mask = p.mask;
                }
            }
            return best_mask;
        }

        class Encoder
        {
        public:
            void init()
            {
#if defined(DECK_TOUCH)
                // Configure encoder A/B pins as inputs with pull-ups
                pinMode(ENC1_A, INPUT_PULLUP);
                pinMode(ENC1_B, INPUT_PULLUP);
                pinMode(ENC2_A, INPUT_PULLUP);
                pinMode(ENC2_B, INPUT_PULLUP);
                pinMode(ENC3_A, INPUT_PULLUP);
                pinMode(ENC3_B, INPUT_PULLUP);
                pinMode(ENC4_A, INPUT_PULLUP);
                pinMode(ENC4_B, INPUT_PULLUP);
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

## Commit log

2024-03-02 Fix build: version and serial are defined twice
    [main.ino]
2024-03-02 Add encoder
2024-03-02 Add Encoders class
2024-05-01 Add image and case model
    [Case - Bottom.stl, Case - Top.stl]
2024-05-01 Add debug feature to reboot into bootsel mode
    [main.ino]
2024-05-01 Add debug feature to reboot
    [main.ino]
2024-05-05 Avoid white screen flashing
    [LCD.hpp]
2024-05-05 Remove unnecessary Serial.print
2024-05-15 Add button border
2024-06-06 Upgrade earlephilhower/arduino-pico to 3.9.0
2024-07-07 Replace Jpeg decoder library to JPEGDEC
    [LCD.hpp]
2024-07-21 Add pico-avrisp-wifi project
2024-07-21 Implement rotary encoder logics
2024-07-21 Revert replace jpeg decoder due to memory
    [LCD.hpp]
2024-07-29 Add tft calibrate data define
2024-07-29 Extract key button point calculations
2024-07-29 Change pin assigning
2024-08-01 Add encoder logics
2024-08-06 Add kicad files for plus
    [Case - Bottom.stl, Case - Top.stl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]
2024-08-06 Add case files for plus
    [Case - Bottom bridge.stl, Case - Top.stl, Case - bottom base.stl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]
2024-08-06 Add pillars to support the screen
    [Bottom body.stl, Case.f3d]
2024-11-19 Add workaround for include build flag
    [LCD.hpp, StreamDeckOriginalMk2Config.hpp, StreamDeckPlusConfig.hpp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]
2025-12-09 Fix HID OUTPUT report handling for TinyUSB 0.17.0+
    [main.ino]
2026-03-07 Plus: Changed to connect the rotary encoder directly to the Pico. Removed the Attiny. - Updated the PCB.
    Co-Authored-By: Claude Sonnet 4.6 <noreply@anthropic.com>
    [Fakedeck-garber-B_Cu.gbr, Fakedeck-garber-B_Mask.gbr, Fakedeck-garber-B_Paste.gbr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]
